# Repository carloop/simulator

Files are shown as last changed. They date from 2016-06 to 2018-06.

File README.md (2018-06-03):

# CAN Simulator

This is a project we used to help develop and test the [Carloop open-source car adapter][carloop]. We hope you'll find it useful for your projects too.

## Overview

The simulator consists of:
- An OBD port (the same you have in your car under the steering wheel) to plug a device to test
- The simulator board to convert CAN voltages to logic levels and provide 12V on the OBD port
- A Raspberry Pi to run the simulator program
- [The program][simulator-program] that communicates with the simulator board and that decide what to do with the CAN messages received

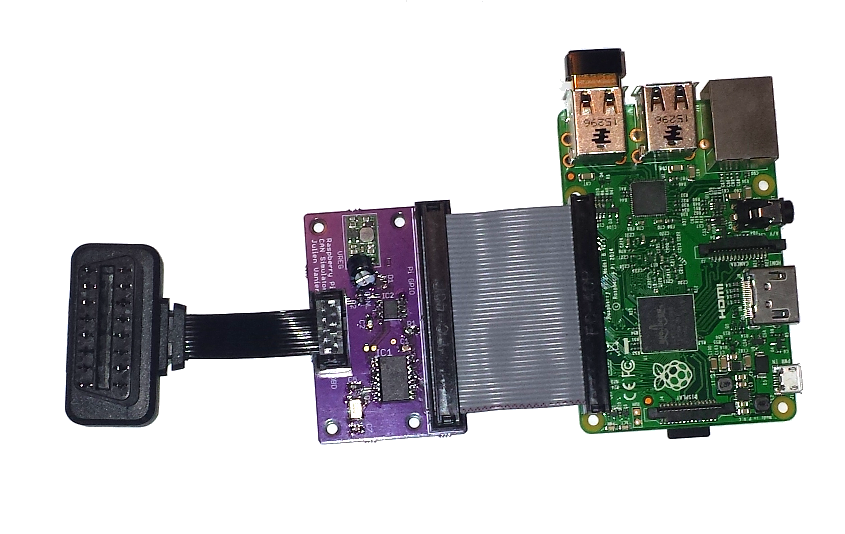
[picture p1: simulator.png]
CAN simulator


## Background about CAN

CAN is the communication bus used between most computers in cars. It has several physical layers, including a high-speed differential voltage (CAN high and CAN low) at up to 1 Mbit/second. CAN is a multicast protocol where each message has an identifier and up to 8 data bytes. Any node listening on the bus can receive any message transmitted. In order to make sense of the messages, the receivers need to know the data format used by the transmitter of each message for the data bytes.

There are higher level protocols built on top of CAN, most importantly ISO 15765 used for OBD-II (On-Board Diagsnotics II) mandated on all cars since 2008 and used on many cars before. See [this tutorial by Sparkfun for more information about the OBD-II protocol][obd-getting-started]

This CAN simulator can be used to transmit and receive messages simulating OBD-II communications and regular vehicle messages.

## Simulator board

The heart of the simulator board is the [MCP2515 standalone CAN controller][mcp2515-datasheet] that understands the CAN protocol
and talks to the Raspberry Pi over the SPI bus.

The board also has a [TJA1049 CAN transceiver][tja1049-datasheet] to translate logic voltage levels to the differential voltage levels used for high speed CAN.

Since the OBD port is supposed to provide 12 volts, a simple [5V to 12V step up regulator from Pololu][12v-step-up-regulator] is included.

The OBD connector is part of an off-the-shelf [9-pin OBD ribbon extension cable available on Amazon][obd-cable].

- [Board schematics (PDF)][schematics] [(Eagle)][schematics-eagle]
- [Board layout (Eagle)][layout-eagle]
- [Bill of materials][bom]
- [MCP2515 CAN controller datasheet][mcp2515-datasheet]
- [TJA1049 CAN transceiver datasheet][tja1049-datasheet]

### Assembly instructions

- [Order a simulator v1 PCB from OSH Park.][pcb-osh-park]
- [Order the parts from the BOM from DigiKey][bom] and the [regulator from Pololu.][12v-step-up-regulator]
- Solder the above together.
- Get a Raspberry Pi with a GPIO connector.
- [Get an OBD cable.][obd-cable]
- Insert the 9-pin flat cable in the 10-pin insulation displacement connector aligned to the left (see the overview picture above) and cut the leftover cable.
- Flash the latest Raspian image to the SD card of your Raspberry PI and follow the instructions to get the simulator program running.

## [Simulator program][simulator-program]

The program running the simulation is in [a separate repository][simulator-program]. Currently it only sends fixed messages. It could be extended for more sophisticated communication or to replay logged CAN bus traces.

## License

Copyright 2016 Julien Vanier. Distributed under the MIT license. See [LICENSE](/LICENSE) for details.

[carloop]: https://www.carloop.io
[simulator-program]: https://github.com/carloop/simulator-program
[schematics]: eagle/CAN-Simulator_v1.1.pdf
[schematics-eagle]: eagle/CAN-Simulator_v1.1.sch
[layout-eagle]: eagle/CAN-Simulator_v1.1.brd
[bom]: eagle/CAN-Simulator_v1_BOM.csv
[obd-getting-started]: https://learn.sparkfun.com/tutorials/getting-started-with-obd-ii
[obd-cable]: https://www.amazon.com/gp/product/B00GGLVXG2/ref=oh_aui_detailpage_o02_s00?ie=UTF8&psc=1
[mcp2515-datasheet]: datasheets/MCP2515%20Datasheet.pdf
[tja1049-datasheet]: datasheets/TJA1049%20Datasheet.pdf
[12v-step-up-regulator]: https://www.pololu.com/product/2117
[pcb-osh-park]:https://oshpark.com/shared_projects/GOPwocjS

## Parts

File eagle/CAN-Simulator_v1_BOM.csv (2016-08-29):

Qty-1 | Part References | Value | Package | Mfg Part Num | Mfg Name | VID | Vendor Part Num | Description | XREF
2 | C2, C1 | 0.1uF | C0805 | 08055C104KAT2A | AVX | DK | 478-1395-1-ND | CAP CER 0.1UF 50V X7R 0805 | REF20
1 | R1 | 4.7K | R0805 | RC0805JR-0747KL | Yageo | DK | 311-47KARCT-ND | RES SMD 47K OHM 5% 1/8W 0805 | REF34
1 | Q1 | 16MHz | CRYSTAL-SMD-5X3 | ABM3B-16.000MHZ-10-1-U-T | Abracon LLC | DK | 300-8206-2-ND | 16MHz ±10ppm Crystal 10pF 50 Ohm -10°C ~ 60°C Surface Mount 4-SMD No Lead (DFN, LCC) | REF33
1 | C5 | 22pF | C0805 | C0805C220J5GACTU | Kemet | DK | 399-1113-1-ND | CAP CER 22PF 50V NP0 0805 | REF29
1 | C7 | 22pF | C0805 | GRM219R61A226MEA0D | Murata | DK | 490-9951-1-ND | CAP CER 22UF 10V X5R 0805 | REF21
1 | R2 | 120 | R0805 | RC0603FR-07120RL | Yageo | DK | 311-120HRCT-ND | RES SMD 120 OHM 1% 1/10W 0603 | REF7
1 | JP1 | AMP 5103308-1 | 2X5-SHROUDED | 5103308-1 | TE Connectivity AMP Connectors | DK | A33159-ND | CONN HEADER LOPRO STR 10POS GOLD | REF31
1 | CONN-JP1 | BOM-ENTRY | * | 1658621-1 | TE Connectivity AMP Connectors | DK | AKC10H-ND | CONN IDC SKT 10POS W/POL 15 GOLD | REF32
1 | IC1 | MCP2515 | SO-18W | MCP2515-I/SO | Microchip | DK | MCP2515-I/SO-ND | IC CAN CONTROLLER W/SPI 18SOIC | REF30
1 | D1 | PESD1CAN | SOT23 | PESD1CAN-215 | NXP Semiconductors | DK | 568-4032-1-ND | TVS DIODE 24VWM 70VC SOT23 | REF2
6 | U1, JP2, STANDOFF1, STANDOFF2, STANDOFF3, STANDOFF4 | STAND-OFF | STAND-OFF | ***PART# '*' NOT FOUND*** | * | * | * | * | *
1 | IC2 | TJA1049 | SO8 | TJA1049T-118 | NXP Semiconductors | DK | 568-8682-1-ND | IC CAN TRANSEIVER HS 8SOIC | REF16

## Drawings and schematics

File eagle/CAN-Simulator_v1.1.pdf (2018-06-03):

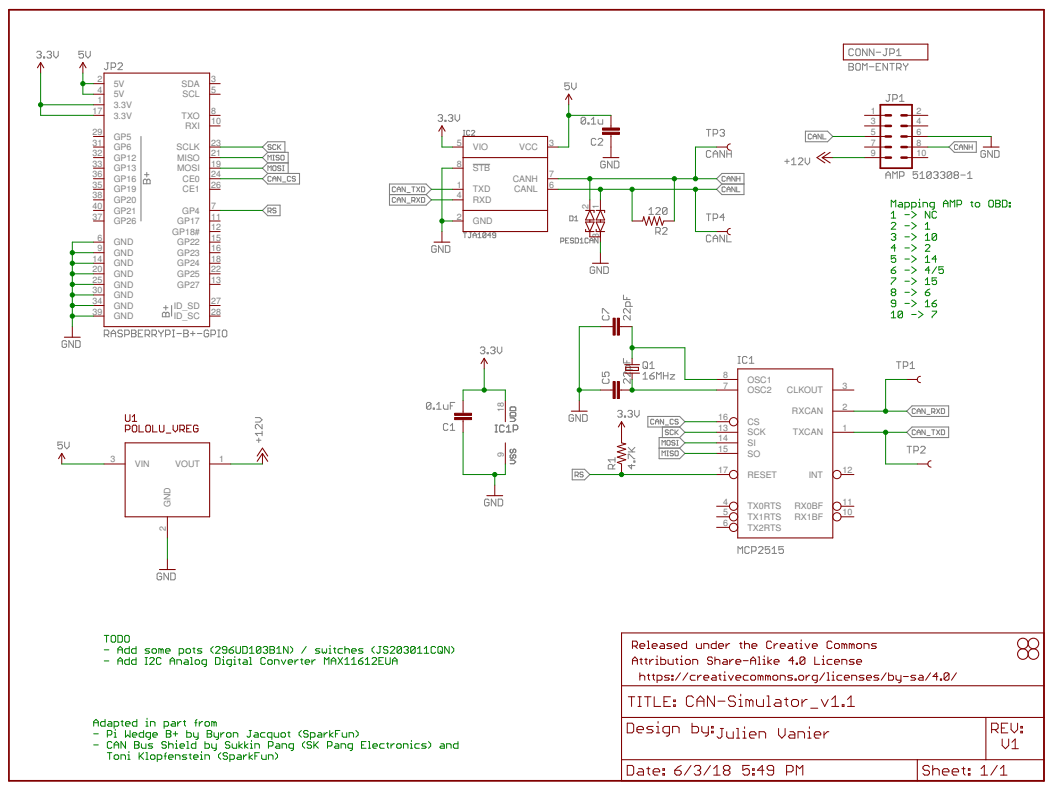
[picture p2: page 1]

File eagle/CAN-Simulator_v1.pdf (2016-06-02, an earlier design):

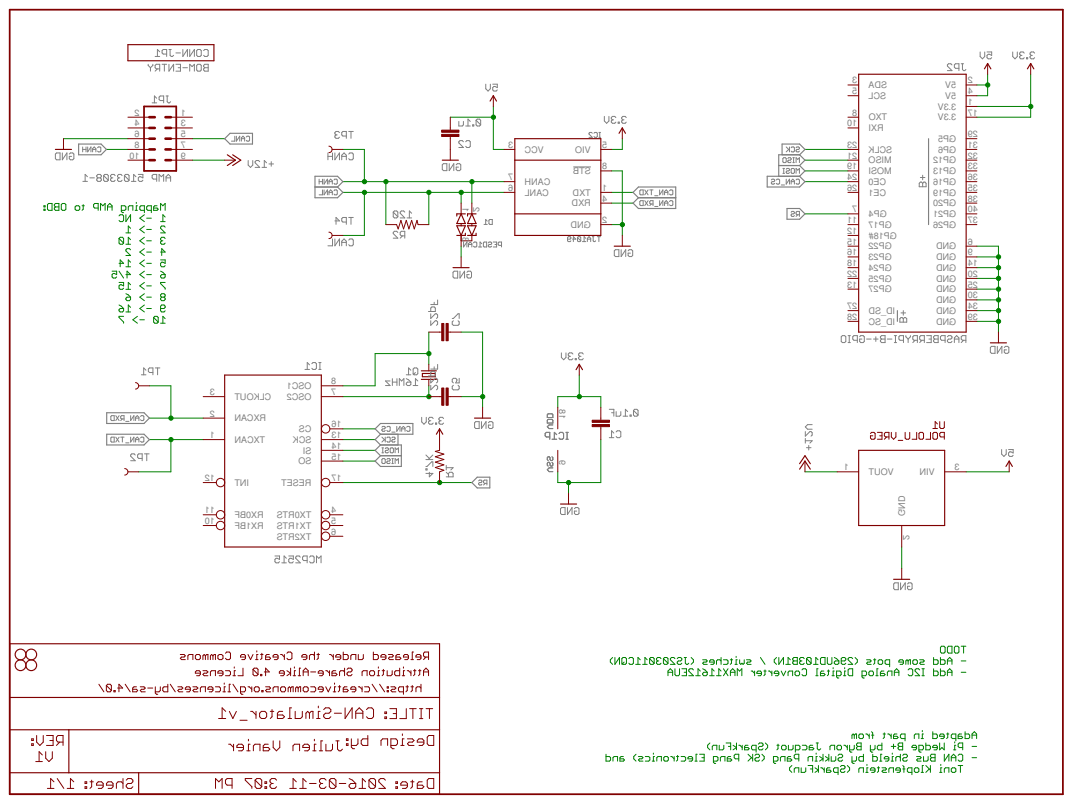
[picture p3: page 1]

V3. 3 1 ADS 3 L CS 5 4PG 7 DNG 9 71PG 11 72PG 31 22PG 51 V3. 3 71 I SOM 91 OSI M 12 KL CS 32 DNG 52 1EC 62 0EC 42 52PG 22 DNG 02 42PG 81 32PG 61 DNG 41 #81PG 21 I XR 01 OXT 8 DNG 6 V5 4 V5 2 DNG 03 DNG 43 DNG 93 DS_ DI 72 CS_ DI 82 5PG 92 6PG 13 21PG 23 31PG 33 91PG 53 61PG 63 62PG 73 02PG 83 12PG 04 TUOKL C 3 SC 61 TNI 21 1 CSO 8 2 CSO 7 TESER 71 FB0XR 11 FB1XR 01 NACXR 2 KCS 31 I S 41 OS 51 STR0XT 4 STR1XT 5 STR2XT 6 NACXT 1 18 9 12 3 BTS 8 HNAC 7 L NAC 6 DNG 2 DXR 4 DXT 1 CCV 3 OI V 5 NI V 3 TUOV 1 GND 2 018642 97531

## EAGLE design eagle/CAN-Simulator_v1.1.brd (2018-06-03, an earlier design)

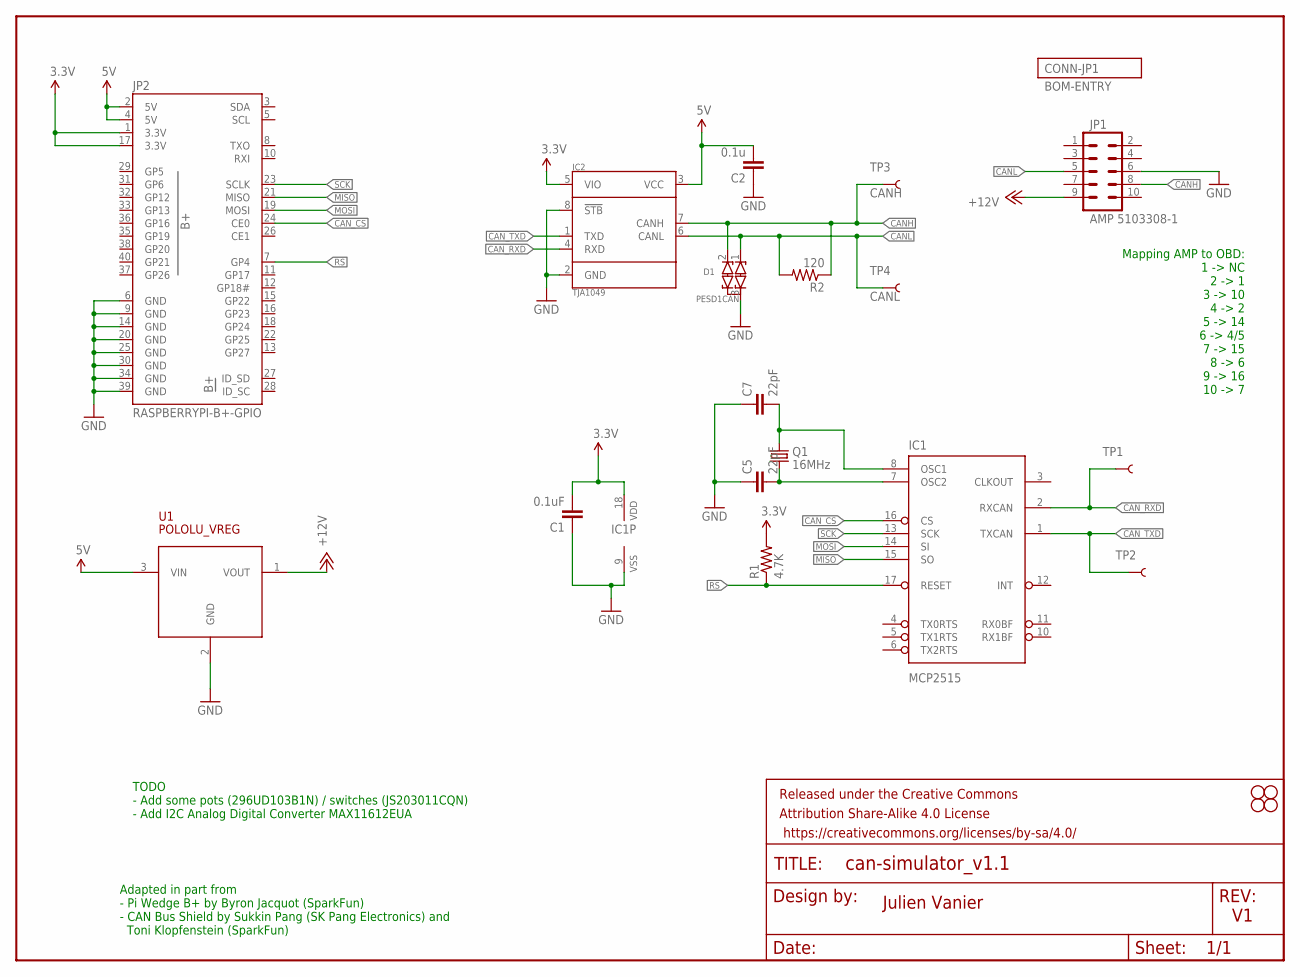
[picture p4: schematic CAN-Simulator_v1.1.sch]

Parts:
C1: 0.1uF; C0805; PARTNO 08055C104KAT2A
C2: 0.1u; C0805; PARTNO 08055C104KAT2A
C5, C7: 22pF; C0805; PARTNO C0805C220J5GACTU
D1: PESD1CAN; SOT23; PARTNO PESD1CAN-215
FRAME1: FRAME-LETTER; CREATIVE_COMMONS
IC1: MCP2515; SO-18W; PARTNO MCP2515-I/SO
IC2: TJA1049; SO8; PARTNO TJA1049T-118
JP1: AMP 5103308-1; 2X5-SHROUDED; PARTNO 5103308-1
JP2: RASPBERRYPI-B+-GPIO; 2X20-SHROUDED
Q1: 16MHz; CRYSTAL-SMD-5X3; PARTNO ABM3B-16.000MHZ-10-1-U-T
R1: 4.7K; R0805; PARTNO RC0805JR-0747KL
R2: 120; R0805; PARTNO RC0603FR-07120RL
STANDOFF1, STANDOFF2, STANDOFF3, STANDOFF4: STAND-OFFSCREW-2; STAND-OFF-2
TP1, TP2: TEST-POINT3X5; PAD.03X.05
TP3: CANH; PAD.03X.03
TP4: CANL; PAD.03X.03
U1: POLOLU_VREG

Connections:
3.3V: C1.2, IC1.18 (VDD), IC2.5 (VIO), JP2.1 (3.3V), JP2.17 (3.3V), R1.2
5V: C2.2, IC2.3 (VCC), JP2.2 (5V), JP2.4 (5V), U1.3 (VIN)
+12V: JP1.9, U1.1 (VOUT)
CANH: D1.2 (C2), IC2.7 (CANH), JP1.8, R2.1, TP3.P$1
CANL: D1.1 (C1), IC2.6 (CANL), JP1.5, R2.2, TP4.P$1
CAN_CS: IC1.16 (CS), JP2.24 (CE0)
CAN_RXD: IC1.2 (RXCAN), IC2.4 (RXD), TP1.P$1
CAN_TXD: IC1.1 (TXCAN), IC2.1 (TXD), TP2.P$1
GND: C1.1, C2.1, C5.1, C7.1, D1.3 (COM), IC1.9 (VSS), IC2.2 (GND), IC2.8 (!STB), JP1.6, JP2.6 (GND), JP2.9 (GND), JP2.14 (GND), JP2.20 (GND), JP2.25 (GND), JP2.30 (GND), JP2.34 (GND), JP2.39 (GND), U1.2 (GND)
MISO: IC1.15 (SO), JP2.21 (MISO)
MOSI: IC1.14 (SI), JP2.19 (MOSI)
unnamed: C7.2, IC1.8 (OSC1), Q1.3 (2)
unnamed: C5.2, IC1.7 (OSC2), Q1.1
RS: IC1.17 (RESET), JP2.7 (GP4), R1.1
SCK: IC1.13 (SCK), JP2.23 (SCLK)

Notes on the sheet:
Julien Vanier
Adapted in part from - Pi Wedge B+ by Byron Jacquot (SparkFun) - CAN Bus Shield by Sukkin Pang (SK Pang Electronics) and Toni Klopfenstein (SparkFun)
TODO - Add some pots (296UD103B1N) / switches (JS203011CQN) - Add I2C Analog Digital Converter MAX11612EUA
Mapping AMP to OBD: 1 -> NC 2 -> 1 3 -> 10 4 -> 2 5 -> 14 6 -> 4/5 7 -> 15 8 -> 6 9 -> 16 10 -> 7

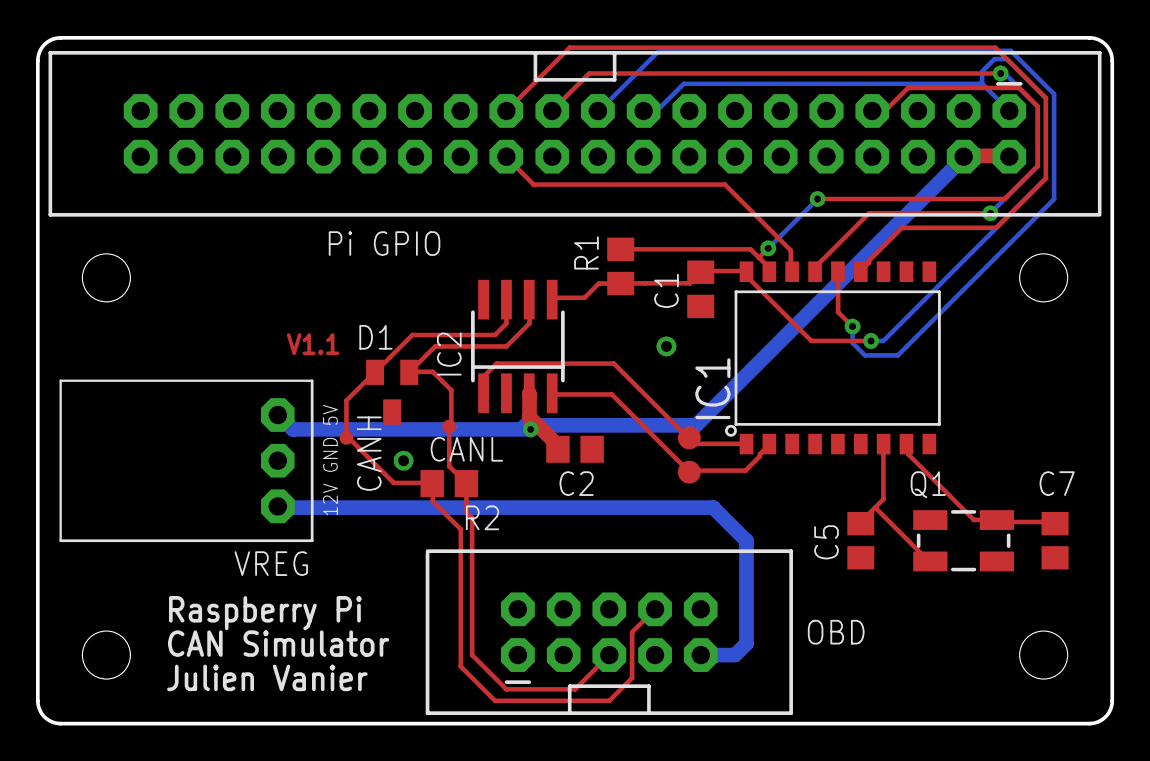
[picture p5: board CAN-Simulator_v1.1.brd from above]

Board: 2 copper layers, 59.7 x 38.1 mm, 22 parts (0 on the bottom side), 15 nets.

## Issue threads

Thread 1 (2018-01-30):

Raspberry PI resets

alan707, 2018-01-30:
The OBD-II port draws too much power from the Pi and it resets the microprocessor.

suggestion from @monkbroc:  put a 12 V barrel jack connector on the shield and a 5V regulator to power the Pi from the shield instead of the other way around.

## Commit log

2016-06-02 Simulator v1 working
    [CAN-Simulator_v1.brd, CAN-Simulator_v1.sch, CAN-Simulator_v1_BOM.csv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]
2016-06-02 Add assembly instructions
2016-08-29 fixed CSV format
    [CAN-Simulator_v1_BOM.csv]
2018-01-30 Work in progress for CAN simulator V2
    [CAN-Simulator_v2.brd, CAN-Simulator_v2.sch]
2018-06-03 Update PCB to 1.1 to distinguish board with corrected transceiver pin 8 ground
    [CAN-Simulator_v1.1.brd, CAN-Simulator_v1.1.sch]

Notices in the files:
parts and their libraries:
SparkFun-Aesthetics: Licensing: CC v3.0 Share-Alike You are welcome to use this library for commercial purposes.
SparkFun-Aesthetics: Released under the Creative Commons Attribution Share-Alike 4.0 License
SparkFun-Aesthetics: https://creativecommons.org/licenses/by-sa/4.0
